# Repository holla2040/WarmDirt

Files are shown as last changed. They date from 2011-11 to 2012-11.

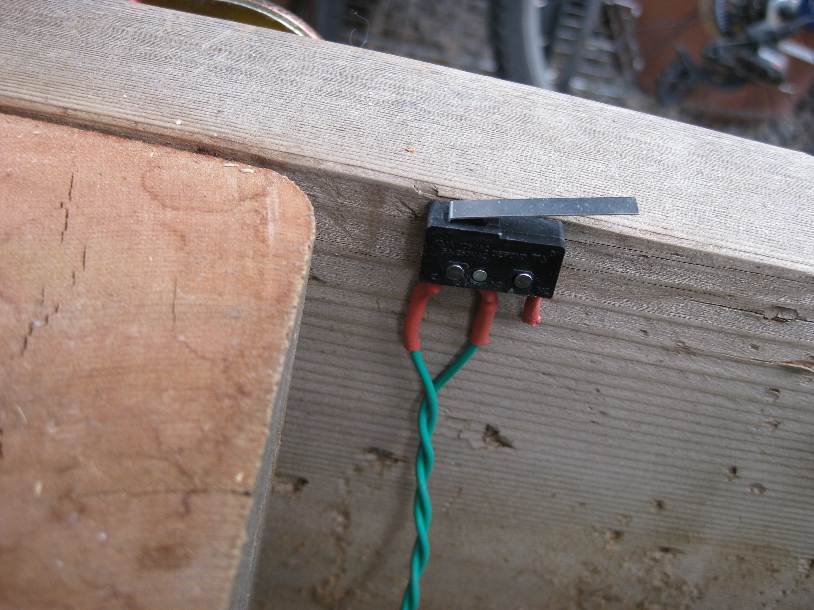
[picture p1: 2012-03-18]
images/120317-155129.jpg

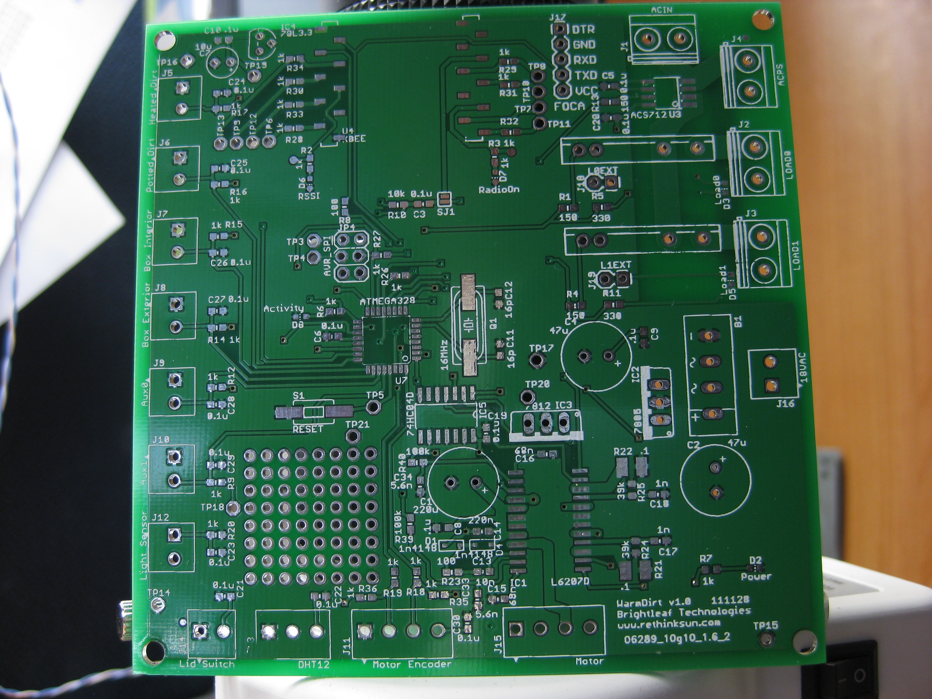
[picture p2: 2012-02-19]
images/111230-093038.jpg

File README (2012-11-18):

WarmDirt - The Greenhouse Box Temperature Controller

Here's a greenhouse box temperature controller for winter growing.
See photos here, http://www.spudcentral.com/potd/120318.html

Requirements
    Sensors
        Temperature 
            Heated dirt
            Potted dirt
            Box interior air
            Box exterior air
            Aux temp 
            Aux temp 
        Humidity 
            Box Interior
        Ambient light
        Lid closed switch
        Heater current monitor

    Control
        Heater 0
        Heater 1
        DC Motor - Stepper or 2 Servos

    Communication
        XBEE

    Framework
        Arduino compatible using ATMEGA328P

ATMEGA328P pin mapping

Pin Port    Descriptions            arduino   WarmDirt 
-----------------------------------------------------------------------
1   PD3     PCINT19 OC2B  INT1 PWM2 D3      | ID  motor encoder b
2   PD4     PCINT20 XCK   T0        D4      | OD  load 0 enable
3   GND                             GND     | P   gnd
4   VCC                             VCC     | P   vcc
5   GND                             GND     | P   gnd
6   VCC                             VCC     | P   vcc
7   PB6     PCINT6  XTAL1 TOSC1     XTAL1   | C   xtal1
8   PB7     PCINT7  XTAL2 TOSC2     XTAL2   | C   xtal2
-----------------------------------------------------------------------
9   PD5     PCINT21 OC0B  T1   PWM0 D5      | O   motor a enable
10  PD6     PCINT22 OC0A  AIN0 PWM0 D6      | O   motor b enable
11  PD7     PCINT23       AIN1      D7      | O   motor a direction
12  PB0     PCINT0  CLKO  ICP1      D8      | O   motor b direction
13  PB1     PCINT1  OC1A       PWM1 D9      | I/O box interior humidity 
14  PB2     PCINT2  OC1B  SS   PWM1 D10     | OD  load 1 enable
15  PB3     PCINT3  OC2A  MOSI PWM2 D11     | ID  lid closed switch
16  PB4     PCINT4        MISO      D12     |
-----------------------------------------------------------------------
17  PB5     PCINT5        SCK       D13     |
18                  AVCC            AVCC    | IA  avcc
19                  ADC6            A6      | IA  ambient light
20                  AREF            AREF    | IA  aref
21  GND                             GND     | P   gnd  
22                  ADC7            A7      | IA  load current
23  PC0     PCINT8  ADC0            A0      | IA  heated dirt temp
24  PC1     PCINT9  ADC1            A1      | IA  potted dirt temp
-----------------------------------------------------------------------
25  PC2     PCINT10 ADC2            A2      | IA  box interior temp
26  PC3     PCINT11 ADC3            A3      | IA  box exterior temp
27  PC4     PCINT12 ADC4  SDA       A4      | IA  aux temp 
28  PC5     PCINT13 ADC5  SCL       A5      | IA  aux temp
29  PC6     PCINT14       RESET     /RESET  | ID  reset
30  PD0     PCINT16       RXD       D0      | ID  rxd to xbee txd
31  PD1     PCINT17       TXD       D1      | OD  txd to xbee rxd
32  PD2     PCINT18       INT0      D2      | ID  motor encoder a
-----------------------------------------------------------------------

v1.1 - proposed (* = implemented)
    * added pot to vrefs on motor driver 
    reworked sense resistor, see Figure 34 in ST AN1762
    * added resistors to +12 regulator to use variable regulator LM1084 5A part
    connected +5 regulator input to +12V to lower power dissipation in +5 reg
    * changed thermistor resistors to 10K
    * added pin 1 marker to L6207D silk
    * changed snubber cap value to 2200pF
    * fixed open hardware on top silk
    * added more isolation around mounting screws
    * changed lightsensor bias resistor to 10K
    * added a LED to lidswitch input
    * added pulldown resistors to motor A/B enables
    changed the interface circuit between cpu and motor enable
    * added motor A and motor B silk label
    added a resistor at xbee dout for foca flashing without xbee removal
    * disconnected the foca vcc from board connector, foca was powering board
    * changed test point names
    added rectifier for AC current measurements per Application 4 - Rectified Output
    * added filter caps to motor encoder signals
    need to use bigger bridge rectifier like GBU8K-BPMS-ND
    LM1084 +12V part has different footprint than 7812
v1.0
    initial addition

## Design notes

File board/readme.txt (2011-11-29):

board
    WarmDirt

version
    1.0

git location
    https://github.com/rethinksun/WarmDirt

description - iteadstudio
    Top layer:                  pcbname.GTL
    Bottom layer:               pcbname.GBL
    Solder Stop Mask top:       pcbname.GTS
    Solder Stop Mask Bottom:    pcbname.GBS
    Silk Top:                   pcbname.GTO
    Silk Bottom:                pcbname.GBO
    NC Drill:                   pcbname.TXT
    readme.txt                  info, has fudicial info

fudicials at
    7.62mm x 7.62mm
    93.98mm x 93.98mm

layer stack up sequence
    top     x.cmp
    bottom  x.sol

contact info
    Craig Hollabaugh
    970 690 4911
    chollabaugh@rethinksun.com

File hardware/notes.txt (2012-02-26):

my stepper motor shaft is 3mm is 118mils 118/2 = 0.059
uprinting requires a .057" hole for attachments

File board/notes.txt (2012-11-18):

to get solder mask fit around prototype area
    set DRC:Masks:Limit=20mil

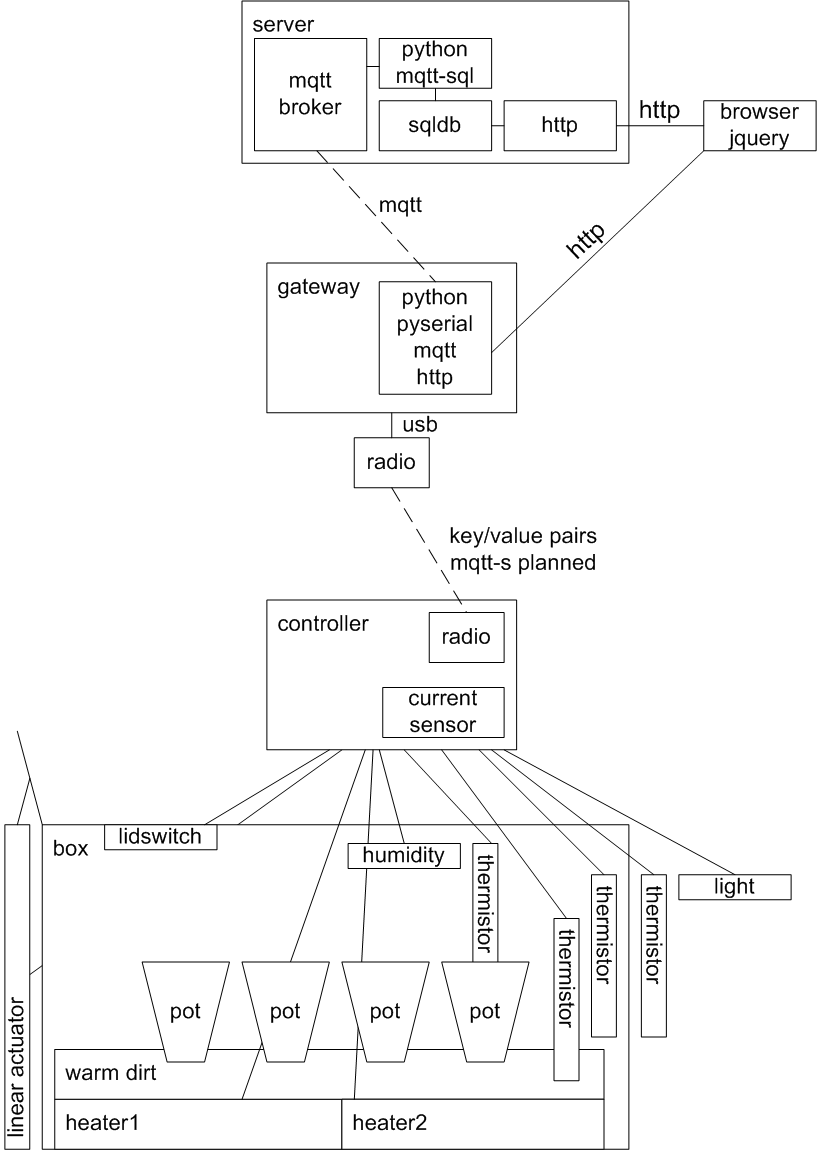
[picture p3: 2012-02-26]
docs/architecture.gif

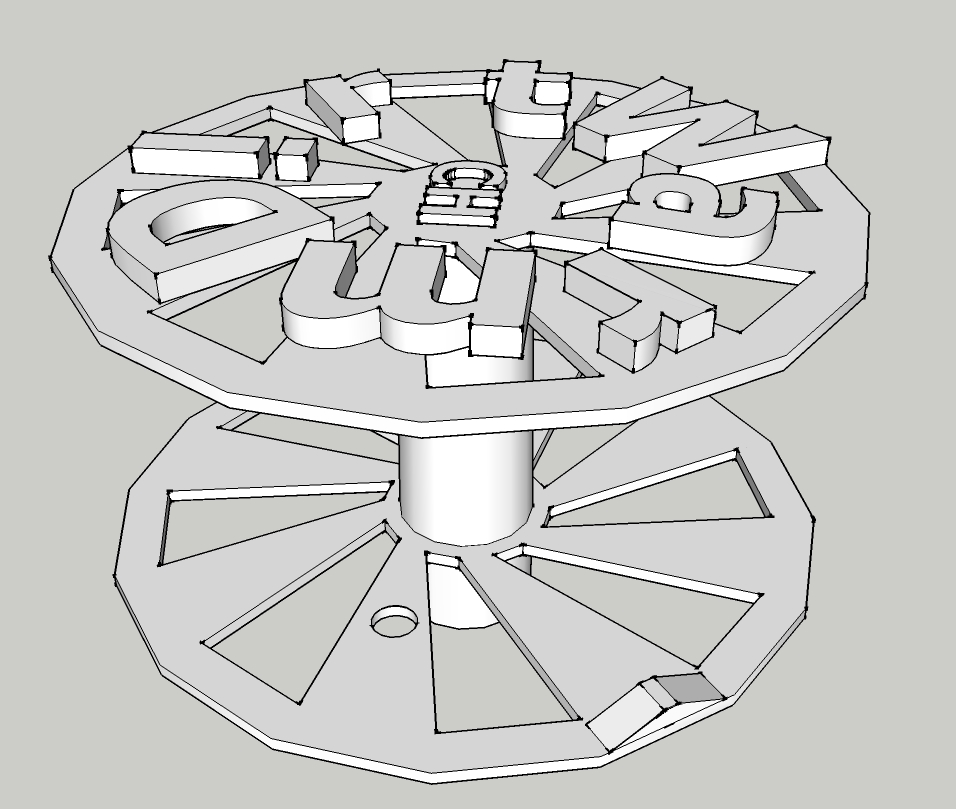
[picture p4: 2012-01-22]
hardware/WarmDirtPulley.jpg

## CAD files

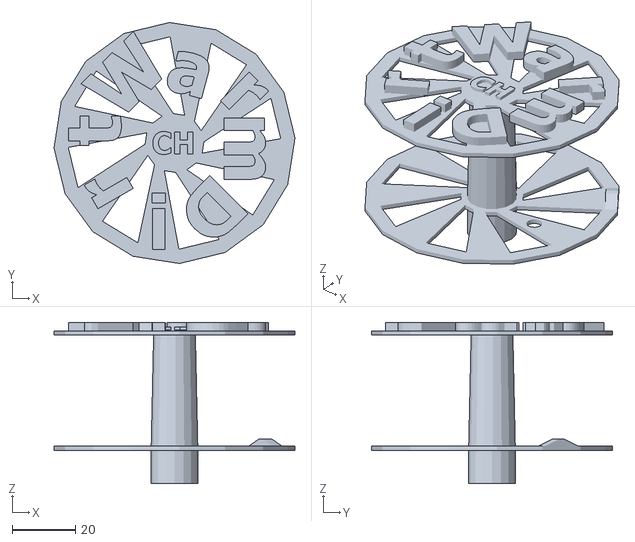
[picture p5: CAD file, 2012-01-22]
hardware/WarmDirtPulley.stl
76.1 x 76.1 x 50.8

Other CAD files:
hardware/WarmDirtPulley.skp

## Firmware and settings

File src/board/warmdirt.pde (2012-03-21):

#include <stdint.h>
#include "WarmDirt.h"
#include "PID_v1.h"

#define STATUSUPDATEINVTERVAL   30000
#define ACTIVITYUPDATEINVTERVAL 500

int lightstate;
#define LIGHTONDURATION             72000L
#define LIGHTTHRESHOLD              500
#define STATELIGHTABOVETHRESHOLD    'a'
#define STATELIGHTON                '1'
#define STATELIGHTOFF               '0'
#define STATELIGHTTEMPON            't'
#define STATELIGHTTEMPONDURATION    600000L

#define LIDUPTHRESHOLD              44.0 
#define LIDDOWNTHRESHOLD            42.5
#define LIDMOVINGTIME               400000L
#define LIDSTATEDOWN                'd'
#define LIDSTATEMOVINGDOWN          'v'
#define LIDSTATEMOVINGUP            '^'
#define LIDSTATEUP                  'u'
uint8_t lidstate;
uint32_t lidMovingTimeout;

uint32_t lightUpdate;

extern PID pid;
double settemp = 55.0;

double pdpidsetpoint, pdpidinput, pdpidoutput;
PID pdpid(&pdpidinput, &pdpidoutput, &pdpidsetpoint,5,0.001,0.01,DIRECT);


char *ftoa(char *a, double f, int precision) {
  long p[] = {0,10,100,1000,10000,100000,1000000,10000000,100000000};

  char *ret = a;
  long heiltal = (long)f;
  itoa(heiltal, a, 10);
  while (*a != '\0') a++;
  *a++ = '.';
  long desimal = abs((long)((f - heiltal) * p[precision]));
  itoa(desimal, a, 10);
  return ret;
}

uint32_t nextIdleStatusUpdate;
uint32_t nextActivityUpdate;

int8_t   speedA = 0;
int8_t   speedB = 0;

char     address = '1';


WarmDirt wd;

void reset() {
    asm volatile("jmp 0x3E00"); /* dont know where I got this but it works on 328 */
}


void setup() {                
    Serial.begin(57600);
    wd.sendPacketKeyValue(address,KV,"/data/setup","1");
    wd.setTemperatureSetPoint(settemp,1);
    lightstate = STATELIGHTOFF;
    pdpid.SetOutputLimits(50,65);
    pdpid.SetMode(AUTOMATIC);
    pdpidsetpoint = 48.0;
    lidstate = LIDSTATEDOWN;
}



void commProcess(int c) {
    switch (c) {
        case 's':
            nextIdleStatusUpdate = 0;
            break;
        case 'R':
            reset();
            break;
        case '5':
            settemp -= 1;
            wd.setTemperatureSetPoint(settemp,1);
            nextIdleStatusUpdate = 0;
            break;
        case '6':
            settemp += 1;
            wd.setTemperatureSetPoint(settemp,1);
            nextIdleStatusUpdate = 0;
            break;
        case 'a':
            Serial.print("a");
            while (!Serial.available()) ;
            c = Serial.read();
            Serial.print((char)c);
            if (c == '0') {
                while (!Serial.available()) ;
                c = Serial.read();
                Serial.print((char)c);
                if (c == '0') {
                    wd.load0Off();
                }
                if (c == '1') {
                    wd.load0On();
                }
            } else {
                if (c == '1') {
                    while (!Serial.available()) ;
                    c = Serial.read();
                    Serial.print((char)c);
                    if (c == '0') {
                        wd.load1Off();
                        lightstate = STATELIGHTOFF;
                    }
                    if (c == '1') {
                        wd.load1On();
                        lightstate = STATELIGHTTEMPON;
                        lightUpdate = millis() + STATELIGHTTEMPONDURATION;
                    }
                }
            }
            Serial.println();
            break;
        case 'i':
            speedB += MOTORSPEEDINC; 
            speedB = wd.motorBSpeed(speedB);
            Serial.print("b = ");
            Serial.println(speedB);
            break;
        case 'k':
            speedB -= MOTORSPEEDINC; 
            speedB = wd.motorBSpeed(speedB);
            Serial.print("b = ");
            Serial.println(speedB);
            break;
        case 'j':
            speedA += MOTORSPEEDINC; 
            speedA = wd.motorASpeed(speedA);
            Serial.print("a = ");
            Serial.println(speedA);
            break;
        case 'l':
            speedA -= MOTORSPEEDINC; 
            speedA = wd.motorASpeed(speedA);
            Serial.print("a = ");
            Serial.println(speedA);
            break;
        case ' ':
            Serial.println("full stop");
            speedA = 0;
            speedB = 0;
            wd.motorASpeed(speedA);
            wd.motorBSpeed(speedB);
            wd.stepperDisable();
            break;
        case '0': // avrdude sends 0-space 
            while (!Serial.available()) ;
            c = Serial.read();
            if (c == ' ') {
                reset();
            }
            break;
        case 'w':
            int i;
            Serial.println("stepper backward");
            wd.stepperSpeed(10);
            wd.stepperEnable();
            delay(10);
            wd.stepperStep(100);
            /*
            for (i = 0; i < 10; i++) { 
                wd.stepperStep(1);
                delay(10);
            }
            */
            delay(10);
            wd.stepperDisable();
            break;
        case 'r':
            Serial.println("stepper forward");
            wd.stepperSpeed(10);
            wd.stepperEnable();
            delay(10);
            wd.stepperStep(100);
            delay(10);
            wd.stepperDisable();
            break;
        case 'd':
            speedB = -100;
            speedB = wd.motorBSpeed(speedB);
            lidMovingTimeout = millis() + LIDMOVINGTIME;
            lidstate = LIDSTATEMOVINGDOWN;
            break;
   }
}

void commLoop() {
    int c;
    if (Serial.available()) {
        c = Serial.read();
        commProcess(c);
    }
}

void statusLoop() {
    char buffer[30];
    uint32_t temp;
    uint32_t now = millis();
    double hd,pd,bi,be,lc,hum,ot;
    if (now > nextActivityUpdate) {
        wd.activityToggle();
        nextActivityUpdate = now + ACTIVITYUPDATEINVTERVAL;
    }

    if (now > nextIdleStatusUpdate) {
        hd  = wd.getHeatedDirtTemperature();
        pd  = wd.getPottedDirtTemperature();
        bi  = wd.getBoxInteriorTemperature();
        be  = wd.getBoxExteriorTemperature();
        ot  = wd.getAux0Temperature();
        lc  = wd.getLoadACCurrent();
//      hum = wd.getDHTHumidity();

        sprintf(buffer,"%ld",now);
        wd.sendPacketKeyValue(address,KV,"/data/uptime",buffer);

        ftoa(buffer,wd.getTemperatureSetPoint(),2);
        wd.sendPacketKeyValue(address,KV,"/data/temperaturesetpoint",buffer);
        delay(100);

        ftoa(buffer,hd,2);
        wd.sendPacketKeyValue(address,KV,"/data/temperatureheateddirt",buffer);
        delay(100);

        ftoa(buffer,pd,2);
        wd.sendPacketKeyValue(address,KV,"/data/temperaturepotteddirt",buffer);
        delay(100);

        ftoa(buffer,bi,2);
        wd.sendPacketKeyValue(address,KV,"/data/temperatureboxinterior",buffer);
        delay(100);

        ftoa(buffer,be,2);
        wd.sendPacketKeyValue(address,KV,"/data/temperatureboxexterior",buffer);
        delay(100);

        ftoa(buffer,ot,2);
        wd.sendPacketKeyValue(address,KV,"/data/temperatureoutside",buffer);
        delay(100);


        sprintf(buffer,"%d",wd.getLightSensor());
        wd.sendPacketKeyValue(address,KV,"/data/lightlevel",buffer);
        delay(100);


        sprintf(buffer,"%d",wd.getLidSwitchClosed());
        wd.sendPacketKeyValue(address,KV, "/data/lidclosed",buffer);
        delay(100);

        if ((lidstate == LIDSTATEMOVINGUP) || (lidstate == LIDSTATEMOVINGDOWN)) {
            temp = lidMovingTimeout - millis();
            sprintf(buffer,"%ld", temp);
            wd.sendPacketKeyValue(address,KV,"/data/lidmovingtimeout",buffer);
            delay(100);
        }

        switch (lidstate) {
            case LIDSTATEDOWN:
                sprintf(buffer,"closed");
                break;
            case LIDSTATEMOVINGUP:
                sprintf(buffer,"opening %ds",temp/1000);
                break;
            case LIDSTATEUP:
                sprintf(buffer,"open");
                break;
            case LIDSTATEMOVINGDOWN:
                sprintf(buffer,"closing %ds",temp/1000);
                break;
        }
        wd.sendPacketKeyValue(address,KV,"/data/lidstate",buffer);
        delay(100);
        
        sprintf(buffer,"%d",wd.bencodercount);
        wd.sendPacketKeyValue(address,KV, "/data/lidencodercount",buffer);
        delay(100);


        sprintf(buffer,"%d",speedB);
        wd.sendPacketKeyValue(address,KV,"/data/lidmotorspeed",buffer);
        delay(100);

        sprintf(buffer,"%d",wd.getLoad0On());
        wd.sendPacketKeyValue(address,KV,"/data/load0on",buffer);
        delay(100);

        sprintf(buffer,"%d",wd.getLoad1On());
        wd.sendPacketKeyValue(address,KV,"/data/load1on",buffer);
        delay(100);

        ftoa(buffer,lc,1);
        wd.sendPacketKeyValue(address,KV,"/data/loadcurrent",buffer);
        delay(100);

        ftoa(buffer,wd.getPIDOutput(),2);
        wd.sendPacketKeyValue(address,KV,"/data/pidoutput",buffer);
        delay(100);

/*
        ftoa(buffer,pid.ppart,2);
        wd.sendPacketKeyValue(address,KV,"/data/pidp",buffer);
        delay(100);

        ftoa(buffer,pid.ipart,2);
        wd.sendPacketKeyValue(address,KV,"/data/pidi",buffer);
        delay(100);

        ftoa(buffer,pid.dpart,2);
        wd.sendPacketKeyValue(address,KV,"/data/pidd",buffer);
        delay(100);

        ftoa(buffer,pdpidoutput,2);
        wd.sendPacketKeyValue(address,KV,"/data/pdpidoutput",buffer);
        delay(100);

        ftoa(buffer,pdpid.ppart,2);
        wd.sendPacketKeyValue(address,KV,"/data/pdpidp",buffer);
        delay(100);

        ftoa(buffer,pdpid.ipart,2);
        wd.sendPacketKeyValue(address,KV,"/data/pdpidi",buffer);
        delay(100);

        ftoa(buffer,pdpid.ipartraw,2);
        wd.sendPacketKeyValue(address,KV,"/data/pdpidiraw",buffer);
        delay(100);

        ftoa(buffer,pdpid.dpart,2);
        wd.sendPacketKeyValue(address,KV,"/data/pdpidd",buffer);
        delay(100);
*/

        switch (lightstate) {
            case STATELIGHTON:
                sprintf(buffer,"timed on %ds",(lightUpdate - millis())/1000);
                break;
            case STATELIGHTOFF:
                sprintf(buffer,"off");
                break;
            case STATELIGHTTEMPON:
                sprintf(buffer,"temp on %ds",(lightUpdate - millis())/1000);
                break;
            case STATELIGHTABOVETHRESHOLD:
                sprintf(buffer,"sunlight %d",wd.getLightSensor());
                break;
        }
        wd.sendPacketKeyValue(address,KV,"/data/lightstate",buffer);
        delay(100);




/*
        ftoa(buffer,hum,1);
        wd.sendPacketKeyValue(address,KV,"/data/humidity",buffer);

        sprintf(buffer,"%d",speedA);
        wd.sendPacketKeyValue(address,KV,"/data/motoraspeed",buffer);

        sprintf(buffer,"%d",speedB);
        wd.sendPacketKeyValue(address,KV,"/data/motorbspeed",buffer);
*/


        nextIdleStatusUpdate = millis() + STATUSUPDATEINVTERVAL;
    }
}

void lightLoop() {
    int l = wd.getLightSensor();
    if (l > (LIGHTTHRESHOLD + 150)) { // 150 is larger than light contribution
        lightstate = STATELIGHTABOVETHRESHOLD;
        wd.load1Off();
        return;
    }
    if (lightstate == STATELIGHTABOVETHRESHOLD) {
        if (l < LIGHTTHRESHOLD) {
            wd.load1On();
            lightstate = STATELIGHTON;
            lightUpdate = millis() + LIGHTONDURATION;
        }
    }
    if (lightstate == STATELIGHTON || lightstate == STATELIGHTTEMPON) {
        if (millis() > lightUpdate) {
            wd.load1Off();
            lightstate = STATELIGHTOFF;
        }
    }
}

void temperatureLoop() {
    pdpidinput = wd.getPottedDirtTemperature();
    pdpid.Compute();
    wd.setTemperatureSetPoint(pdpidoutput,1);
}

void lidLoop() {
    double be  = wd.getBoxExteriorTemperature();
    switch (lidstate) {
        case LIDSTATEDOWN:
            if ( be > LIDUPTHRESHOLD ) {
                speedB = 100;
                speedB = wd.motorBSpeed(speedB);
                lidMovingTimeout = millis() + LIDMOVINGTIME;
                lidstate = LIDSTATEMOVINGUP;
            }
            break;
        case LIDSTATEMOVINGUP:
            if (millis() > lidMovingTimeout) {
                speedB = 0;
                speedB = wd.motorBSpeed(speedB);
                lidstate = LIDSTATEUP;
            }
            break;
        case LIDSTATEUP:
            if ( be < LIDDOWNTHRESHOLD ) {
                speedB = -100;
                speedB = wd.motorBSpeed(speedB);
                lidMovingTimeout = millis() + LIDMOVINGTIME;
                lidstate = LIDSTATEMOVINGDOWN;
            }
            break;
        case LIDSTATEMOVINGDOWN:
            if (millis() > lidMovingTimeout) {
                speedB = 0;
                speedB = wd.motorBSpeed(speedB);
                lidstate = LIDSTATEDOWN;
            }
            break;
    }
}

void loop() {
    statusLoop();
    commLoop();
    wd.loop();
    lightLoop();
    temperatureLoop();
    lidLoop();
}

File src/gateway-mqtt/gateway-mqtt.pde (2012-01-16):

#include <SPI.h>
#include <Ethernet.h>
#include <PubSubClient.h>
#include <string.h>
#include "NewSoftSerial.h"
#include "socket.h"

#define UPTIMEUPDATEINTERVAL   55000
#define MQTTRECONNECTINTERVAL  300000L

#define LOCATION 1

#if LOCATION == 0

#define MQTTUSER    "121warmdirt1"
#define MQTTPREFIX  "us/co/montrose/121 Apollo/warmdirt"
#define MQTTLOC     "us/co/montrose/121 Apollo"

#else

#define MQTTUSER    "1001warmdirt1"
#define MQTTPREFIX  "us/co/montrose/1001s2nd/warmdirt"
#define MQTTLOC     "us/co/montrose/1001s2nd"

#define STX         2
#define ETX         3

#endif

uint32_t nextUptimeUpdate;
uint32_t tcpTimeout;
uint32_t nextMqttReconnect;

/* 
    print debug log connect usb-ftdi-RX to A0 at 9600 8N1
*/


byte mac[] =        { 0xDE, 0xAD, 0x42, 0xEF, 0xFE, 0xED };

#if LOCATION == 0
byte ip[] =         { 10,210,211,249 };
byte mqttserver[] = { 10,210,211,231 };
byte gateway[] =    { 10,210,211,1   };
#else
byte ip[] =         { 192,168,0,10  };
byte mqttserver[] = { 192,168,0,117 };
byte gateway[] =    { 192,168,0,1   };
#endif

char line[100];
char key[100];
char lineindex;
char c;

char mqttconnected; 

NewSoftSerial debug(A1,A0);

void mqttprocess(char *topic, byte * payload, int length) {
    char *topicwithoutprefix = topic + strlen(MQTTPREFIX) + 1; // +1 for trailing '/'
    payload[length] = 0; // payload is a pointer in 'buffer[128]'
    Serial.print(topicwithoutprefix);
    Serial.print("=");
    Serial.println((char *)payload);
    debug.print("mrecieved ");
    debug.print(topicwithoutprefix);
    debug.print("=");
    debug.println((char *)payload);
}

PubSubClient mqtt(mqttserver, 1883, mqttprocess);

Server tcpserver(1055);

void publish(char *prefix, char *k,char *v) {
    sprintf(key,"%s/%s",prefix,k);
    mqtt.publish(key,v);
    sprintf(key,"published %s/%s=%s",MQTTPREFIX,k,v);
    debug.println(key);
}


void mqttconnect() {
    sprintf(line,"mqtt connect %s@%d.%d.%d.%d:1883 ",MQTTUSER,mqttserver[0],mqttserver[1],mqttserver[2],mqttserver[3]);
    debug.print(line);
    if (mqtt.connect(MQTTUSER)) {
        debug.println("success");

        sprintf(line,"%s/+/config/#",MQTTPREFIX);
        mqtt.subscribe(line);
        debug.print("subscribed to ");
        debug.println(line);

        publish(MQTTLOC,"gateway/begin","1");

        mqttconnected = 1;
    } else {
        debug.println("failure");
        mqttconnected = 0;
    }
}

void restartNetwork() {
    mqtt.disconnect();
    Ethernet.begin(mac, ip, gateway);
    delay(2500); // wait a bit for wiz to come up
    tcpserver.begin();
    mqttconnect();
}

void setup() {
    Serial.begin(57600);
    debug.begin(38400);
    debug.println("\n\nwarmdirtgatewaymqtt setup");

    Ethernet.begin(mac, ip, gateway);
    delay(2500); // wait a bit for wiz to come up
    tcpserver.begin();
    lineindex = 0;
    nextUptimeUpdate = 0;
    nextMqttReconnect = millis() + MQTTRECONNECTINTERVAL;
    mqttconnect();
}


void mqttloop() {
    uint32_t now = millis();
    if (now > nextMqttReconnect || mqtt.loop() == 0) {
        restartNetwork();
        nextMqttReconnect = now + MQTTRECONNECTINTERVAL;
    }
}

void commloop() {
    int c;
    char tcpc;
    uint32_t now = millis();

    Client client = tcpserver.available();
    if (client) {
        tcpTimeout = now + 30000;
        for (;;) {
            if (client) {
                tcpc = client.read();
                if (tcpc != -1) {
                    Serial.print(tcpc);
                    //debug.print(">");
                    //debug.println(tcpc,HEX);
                }
                if (Serial.available()) {
                    c = Serial.read();
                    tcpserver.write(c);
                    //debug.print("<");
                    //debug.println(c,HEX);
                }
                if (millis() > tcpTimeout) {
                    break;
                }
            }
            Client client = tcpserver.available();
        }
    }

    if (Serial.available()) {
        c = Serial.read();
        if (c == STX) {
            lineindex = 0;
            return;
        }
        if (c == '\r' || c == '\n') {
            return;
        }
        if (c == ETX) {
            line[lineindex] = 0;
            //debug.print("srecieved ");
            //debug.println(line);
            publish(MQTTPREFIX,strtok(line,"="),strtok(NULL,"="));
            return;
        }
        line[lineindex++] = c;
    }
}

void statusloop() {
    unsigned long now = millis();
    char v[40];

    if (now > nextUptimeUpdate) {
        sprintf(v,"%lu",now);
        publish(MQTTLOC,"gateway/uptime",v);
        nextUptimeUpdate = now + UPTIMEUPDATEINTERVAL;
    }
}

void loop() {
    mqttloop();
    commloop();
    statusloop();
}

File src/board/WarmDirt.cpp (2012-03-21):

#include "WProgram.h"
#include <stdint.h>
#include <util/crc16.h>
#include <avr/eeprom.h>
#include "PID_v1.h"

#include "WarmDirt.h"
#include "DHT.h"
#include "Stepper.h"

#define DHTPIN  9
#define DHTTYPE DHT11 


enum {EETC,EETSP,EETH};

DHT dht(DHTPIN, DHTTYPE);
Stepper stepper(15,PINMOTORAIN,PINMOTORBIN);

double pidsetpoint, pidinput, pidoutput; 
PID pid(&pidinput, &pidoutput, &pidsetpoint,3000,1,1,DIRECT);

int windowSize = 5000;
unsigned long windowStartTime;

/* see http://stackoverflow.com/questions/4709127/c-gcc-cant-find-static-member-when-linking */
/* also search for 'static member functions' */
int32_t WarmDirt::bencodercount;
int8_t  WarmDirt::bdirection;
void WarmDirt::countBUpdate() {
    bencodercount += bdirection;
}

WarmDirt::WarmDirt(double srhd, double srpd, double srbi, double srbe, double sra0, double sra1) {
    seriesResistorHeatedDirt   = srhd;
    seriesResistorPottedDirt   = srpd;
    seriesResistorBoxInterior  = srbi;
    seriesResistorBoxExterior  = srbe;
    seriesResistorAux0         = sra0;
    seriesResistorAux1         = sra1;

    pinMode(PINLIDSWITCH,   INPUT);
    pinMode(PINACTIVITY,    OUTPUT);

    pinMode(PINLOAD0ENABLE, OUTPUT);
    pinMode(PINLOAD1ENABLE, OUTPUT);

/* motor driver can drive 2 servos or 1 stepper */
    pinMode(PINMOTORAIN,        OUTPUT);
    pinMode(PINMOTORAENABLE,    OUTPUT); /* pwm */
    pinMode(PINMOTORBIN,        OUTPUT); 
    pinMode(PINMOTORBENABLE,    OUTPUT); /* pwm */

    digitalWrite(PINACTIVITY, HIGH);

    load0Off(); 
    load1Off(); 

    motorASpeed(0);
    motorBSpeed(0);
    stepperSpeed(100);

    setPwmFrequency(F977); /* arduino code sets to F977 for millis and delay to function, change at your own risk */

    dht.begin();

    windowStartTime = millis();

    //eeprom_write_byte(0, '2');
    //id = eeprom_read_byte(0);

    attachInterrupt(0, &WarmDirt::countBUpdate, CHANGE);
    bencodercount = 0;
}

void WarmDirt::debug() {
    Serial.print("pid mode ");
    Serial.println(pid.GetMode());

}

uint16_t WarmDirt::adcaverage(uint8_t pin, uint16_t samples) {
    uint32_t sum = 0;
    uint16_t i;

    for (i = 0; i < samples; i++) {
        sum += analogRead(pin);
        delay(5);
    }
    return sum / samples;
}

/* http://arduino.cc/en/Reference/AnalogRead 
    It takes about 100 microseconds (0.0001 s) to read an analog input, so the maximum reading rate is about 10,000 times a second.
    samples = 166 reads an entire AC 60Hz wave
*/
uint16_t WarmDirt::adcmax(uint8_t pin, uint16_t samples) {
    uint16_t i,max,normalizedvalue;
    for (i = 0; i < samples; i++) {
        normalizedvalue = abs(analogRead(pin) - 511);
        if (normalizedvalue > max) {
            max = normalizedvalue;
        }
    }
    return max;
}

double  WarmDirt::getPIDOutput() {
    return pidoutput;
}

double  WarmDirt::adctotemp(uint16_t adc, double seriesResistance) {
    double steinhart;
    double thermalr;

    thermalr = 1023.0 / float(adc) - 1;
    thermalr = seriesResistance / thermalr;
 
    steinhart = thermalr / THERMISTORNOMINAL;         // (R/Ro)
    steinhart = log(steinhart);                       // ln(R/Ro)
    steinhart /= BCOEFFICIENT;                        // 1/B * ln(R/Ro)
    steinhart += 1.0 / (TEMPERATURENOMINAL + 273.15); // + (1/To)
    steinhart = 1.0 / steinhart;                      // Invert
    steinhart -= 273.15;                              // convert to C
    steinhart = ctof(steinhart);                      // convert to f
    return steinhart;
}

double WarmDirt::ctof(double c) {
    return 9.0*c/5.0+32.0; 
}

double  WarmDirt::getHeatedDirtTemperature() {
    return adctotemp(adcaverage(PINHEATEDDIRT,SAMPLES),seriesResistorHeatedDirt);
}

double  WarmDirt::getPottedDirtTemperature() {
    return adctotemp(adcaverage(PINPOTTEDDIRT,SAMPLES),seriesResistorPottedDirt);
}

double  WarmDirt::getBoxInteriorTemperature() {
    return adctotemp(adcaverage(PINBOXINTERIOR,SAMPLES),seriesResistorBoxInterior);
}

double  WarmDirt::getBoxExteriorTemperature() {
    return adctotemp(adcaverage(PINBOXEXTERIOR,SAMPLES),seriesResistorBoxExterior);
}

double  WarmDirt::getAux0Temperature() {
    return adctotemp(adcaverage(PINAUX0,SAMPLES),seriesResistorAux0);
}

double  WarmDirt::getAux1Temperature() {
    return adctotemp(adcaverage(PINAUX1,SAMPLES),seriesResistorAux1);
}

/* ref http://www.ladyada.net/learn/sensors/cds.html */
uint16_t  WarmDirt::getLightSensor() {
    return adcaverage(PINLIGHTSENSOR,SAMPLES);
}

boolean WarmDirt::getLidSwitchClosed() {
    return !digitalRead(PINLIDSWITCH);
}

/* ref http://www.ladyada.net/learn/sensors/dht.html */
double  WarmDirt::getDHTTemperature() {
    return ctof(dht.readTemperature());
}

double  WarmDirt::getDHTHumidity() {
    return dht.readHumidity();
}

double  WarmDirt::getLoadDCCurrent() {
    return adcaverage(PINLOADCURRENT,SAMPLES);
}

double  WarmDirt::getLoadACCurrent() {
    return adcmax(PINLOADCURRENT,200);
}

void    WarmDirt::load0Off() {
/*
    if (digitalRead(PINLOAD0ENABLE) == LOW) {
        sendPacketKeyValue('1',KV,"/data/load0on","0");
    }
*/
    digitalWrite(PINLOAD0ENABLE,HIGH);
}

void    WarmDirt::load0On() {
/*
    if (digitalRead(PINLOAD0ENABLE) == HIGH) {
        sendPacketKeyValue('1',KV,"/data/load0on","1");
    }
*/
    digitalWrite(PINLOAD0ENABLE,LOW);
}

boolean WarmDirt::getLoad0On() {
    return !digitalRead(PINLOAD0ENABLE);
}

void    WarmDirt::load1Off() {
    digitalWrite(PINLOAD1ENABLE,HIGH);
}

void    WarmDirt::load1On() {
    digitalWrite(PINLOAD1ENABLE,LOW);
}

boolean WarmDirt::getLoad1On() {
    return !digitalRead(PINLOAD1ENABLE);
}

void    WarmDirt::activityToggle() {
    digitalWrite(PINACTIVITY,!digitalRead(PINACTIVITY));
}

int8_t  WarmDirt::motorASpeed(int8_t speed) {
    uint8_t duty;
    if (speed > 100) {
        speed = 100;
    }
    if (speed < -100) {
        speed = -100;
    }

    if (speed == 0) {
        digitalWrite(PINMOTORAENABLE,LOW);
    } else {
        if (speed > 0) {
            digitalWrite(PINMOTORAIN,HIGH);
        } else {
            digitalWrite(PINMOTORAIN,LOW);
        }
        duty = map(abs(speed), 0, 100, 0, 255);
        //Serial.println(duty,DEC);
        analogWrite(PINMOTORAENABLE,duty);
    }
    return speed;
}
    

int8_t  WarmDirt::motorBSpeed(int8_t speed) {
    uint8_t duty;
    if (speed > 100) {
        speed = 100;
    }
    if (speed < -100) {
        speed = -100;
    }

    if (speed == 0) {
        digitalWrite(PINMOTORBENABLE,LOW);
    } else {
        if (speed > 0) {
            bdirection = DIRECTIONUP;
            digitalWrite(PINMOTORBIN,HIGH);
        } else {
            bdirection = DIRECTIONDOWN;
            digitalWrite(PINMOTORBIN,LOW);
        }
        duty = map(abs(speed), 0, 100, 0, 255);
        //Serial.println(duty,DEC);
        analogWrite(PINMOTORBENABLE,duty);
    }
    return speed;
}
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

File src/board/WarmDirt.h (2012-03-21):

#ifndef WARMDIRT_H
#define WARMDIRT_H 1

#include "WProgram.h"
#include <stdint.h>

#define PINHEATEDDIRT       A0
#define PINPOTTEDDIRT       A1
#define PINBOXINTERIOR      A2
#define PINBOXEXTERIOR      A3
#define PINAUX0             A4
#define PINAUX1             A5
#define PINLIGHTSENSOR      A6
#define PINLOADCURRENT      A7

#define PINMOTORAIN         7
#define PINMOTORAENABLE     5
#define PINMOTORBIN         8
#define PINMOTORBENABLE     6

#define PINLIDSWITCH        11
#define PINACTIVITY         13
#define PINLOAD0ENABLE      4
#define PINLOAD1ENABLE      10

#define SAMPLES             10

/* ref http://www.ladyada.net/learn/sensors/thermistor.html */
#define THERMISTORNOMINAL   10000      
#define TEMPERATURENOMINAL  25   
#define BCOEFFICIENT        3950

#define MOTORSPEEDINC       5

#define STX         2
#define ETX         3
#define KV  'm'

#define DIRECTIONUP              1
#define DIRECTIONDOWN            -1

enum{F62500,F7813,F977,F244,F61};
/** Frequencies available
    timer 0 - pins 5,6 - 62500Hz
    1       F62500
    8       F7813
    64      F977
    256     F244
    1024    F61
*/

class WarmDirt {
    public:
        WarmDirt(double srhd = 10000, double srpd = 10000, double srbi = 10000, double srbe = 10000, double sra0 = 10000, double sra1 = 10000);
        double      getHeatedDirtTemperature();
        double      getPottedDirtTemperature();
        double      getBoxInteriorTemperature();
        double      getBoxExteriorTemperature();
        double      getAux0Temperature();
        double      getAux1Temperature();
        uint16_t    getLightSensor();
        boolean     getLidSwitchClosed();
        double      getDHTTemperature();
        double      getDHTHumidity();
        double      getLoadDCCurrent();
        double      getLoadACCurrent();
        
        void        load0On();
        void        load0Off();
        boolean     getLoad0On();

        void        load1On();
        void        load1Off();
        boolean     getLoad1On();

        int8_t      motorASpeed(int8_t speed);
        int8_t      motorBSpeed(int8_t speed);
        void        setPwmFrequency(uint8_t frequency);

        void        activityToggle();

        double      ctof(double c);
        void        stepperSpeed(int32_t speed);
        void        stepperStep(int16_t steps);
        void        stepperEnable();
        void        stepperDisable();

        void        sendString(char *str);
        void        sendPacket(uint8_t address, char type, char *str);
        void        sendPacketKeyValue(uint8_t address, char type, char *key, char *value);
        void        loop();
        void        temperatureLoop();
        void        setTemperatureControl(boolean value);
        void        setTemperatureSetPoint(double value, int8_t hysteresis);
        double      getTemperatureSetPoint();
        double      getPIDOutput();
        void        debug();
        static int32_t     bencodercount;

    private:
        uint16_t    adcaverage(uint8_t pin, uint16_t samples);
        uint16_t    adcmax(uint8_t pin, uint16_t samples);
        double      adctotemp(uint16_t adc,double seriesResistance);
        double      seriesResistorHeatedDirt;
        double      seriesResistorPottedDirt;
        double      seriesResistorBoxInterior;
        double      seriesResistorBoxExterior;
        double      seriesResistorAux0;
        double      seriesResistorAux1;
        boolean     temperatureControl;  // should be persisted in EEPROM
        double      temperatureSetPoint; // should be persisted
        double      temperatureHysteresis; // should be persisted
        static void   countBUpdate();
        static int8_t bdirection;
};

#endif

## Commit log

2011-11-13 added heater current monitoring requirement
2011-11-13 initial add for board schematic and layout
    [WarmDirt.brd, WarmDirt.sch]
2011-11-13 initial add for SSR replaced mechanical relay with SSR
2011-11-13 replaced mechanical relay with SSR
    [WarmDirt.brd, WarmDirt.sch]
2011-11-14 replaced l298 with l6207
    [WarmDirt.brd, WarmDirt.sch]
2011-11-14 cleaned up the pin mapping for the tqfp
2011-11-14 initial pin mapping complete
2011-11-14 added additional temperature sensors and another heater control gitignore ignores eagles backup files
    [WarmDirt.brd, WarmDirt.sch]
2011-11-16 wired the AC control added connectors for external power transformer removed the lipo charger and battery connections removed the motor driver diodes, l6207 integrated in
    [WarmDirt.brd, WarmDirt.sch]
2011-11-18 added more connectors
    [WarmDirt.brd, WarmDirt.sch]
2011-11-18 added temperature sensor connectors
    [WarmDirt.brd, WarmDirt.sch]
2011-11-18 added motor driver, clean up of crais's tools, added SHT11 to
    [WarmDirt.brd, WarmDirt.sch]
2011-11-19 initial board placement
    [WarmDirt.brd, WarmDirt.sch]
2011-11-19 added png for board, updated sch
2011-11-20 more clean up, added pull ups, caps, etc.
    [WarmDirt.brd, WarmDirt.sch]
2011-11-20 made name changes
    [WarmDirt.brd, WarmDirt.sch]
2011-11-21 fixed silkscreen
    [WarmDirt.brd, WarmDirt.sch]
2011-11-21 added foca connector added oshw logo
    [WarmDirt.brd, WarmDirt.sch]
2011-11-21 added connector header for external Load Enable LEDs
    [WarmDirt.brd, WarmDirt.sch]
2011-11-29 verified L6207 connections added ENA/ENB filter Added SSR snubber Changed L6207 filter cap value to 200u fixed potential L6207 gnd plane issues moved connector labels to board edge, got my fingers cr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
    [WarmDirt.brd, WarmDirt.sch]
2011-11-29 v1.0 board submission
    [WarmDirt.brd, WarmDirt.sch]
2011-11-29 prepping for itead board submission using their dru and cam files, see zip
    [WarmDirt.brd]
2011-12-15 initial add
    [bomdb.tsv]
2011-12-16 changed values for bom consolation
    [WarmDirt.brd, WarmDirt.sch, bomdb.tsv]
2011-12-30 added more bug fixes to v1.1 fixed consistency issue with schematic
    [WarmDirt.brd, WarmDirt.sch]
2011-12-30 initial add for datasheets, added code for thermistor and lightsensor, added more corrections to v1.1
    [WarmDirt.cpp, WarmDirt.h, test.pde]
2011-12-30 added DHT class from ladyada, added dht support, commLoop with reset and status
    [DHT.cpp, WarmDirt.cpp, WarmDirt.h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]
2011-12-30 added loadcurrent adc support
2011-12-30 added motor a and b support
2011-12-31 now collecting the status data then printing
2012-01-01 added more hardward bugs, fixed gateway key prefix, fixed wd motorbspeed key
    [test.pde, warmdirtgatewaymqtt.pde]
2012-01-02 tried to add tcp server for arduino firmware update via avrdude tcp connection, not ready yet
2012-01-03 for board, see '*'ed items for changes to hardware, other wise bootloader hacking
    [WarmDirt.brd, WarmDirt.sch]
2012-01-08 added lipo circuit reference
2012-01-15 added stepper support
2012-01-15 stepper support now functional
2012-01-23 just hacking on stepper motor stuff
2012-01-23 added temperature control
2012-01-23 moved the setpoint printout
2012-01-24 added DC and AC load current
2012-01-24 added heater to display
2012-01-24 changed process variable to heateddirt, removed debug info
2012-01-24 added pid controller
2012-01-24 hacked on pid
2012-01-24 tweaking pid
2012-01-26 added mqtt.loop check wrapper, went back to heateddirt temp being pv
2012-02-05 more tweaking on pid
2012-02-14 initial add for PID* added avr-size for all: target makefile points to /opt/arduino-0022
2012-02-19 added 'Heated Set' in extral
2012-02-19 added outer PID loop
2012-02-26 added temperatureoutside
2012-03-18 added linear actuator lid control
2012-03-18 added images of linear actuator
2012-03-19 moved lid switch info into label
2012-03-21 added filter caps to motor encoder signals
    [WarmDirt.brd, WarmDirt.sch]
2012-03-21 added motor b/int 0 reed switch counter
2012-03-21 images now contain motor encoder signal filter caps
2012-03-27 added vrefs pots to schematic, not placed or routed yet.
    [WarmDirt.brd, WarmDirt.sch]
2012-03-27 placed and routed motor driver vref pots
    [WarmDirt.brd, WarmDirt.sch]
2012-03-27 added resistors to +12 regulator to use variable regulator LM1084 5A part connected +5 regulator input to +12V to lower power dissipation in +5 reg added pulldown resistors to motor A/B enables
    [WarmDirt.brd, WarmDirt.sch]
2012-03-27 don't know the sch change
    [WarmDirt.sch]
